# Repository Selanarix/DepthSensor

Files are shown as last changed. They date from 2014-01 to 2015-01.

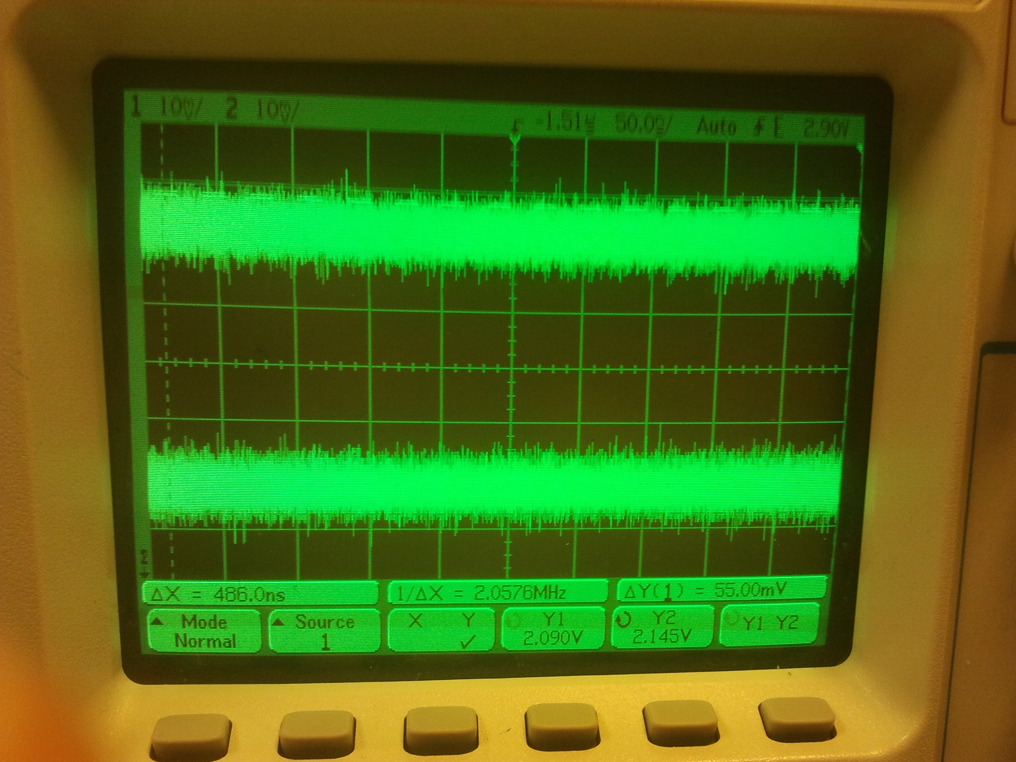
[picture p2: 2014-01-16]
pictures/MPX2100DP oszi/IMG_20140116_185502.jpg

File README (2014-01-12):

DepthSensor Project
====================

Copyright (c) 2014 Jonathan Schubert and Maximilian Hempe

About the repo
--------------
This repository contains code to realise a depth sensor by using an arduino uno and a differential pressure sensor. By transfering the pressure to water depth (1cm=1hPa) the arduino messures the water depth and gives it to a server, which produces a graph on a webpage. We do not give any garantee, but in tests it worked very well.

Purpose
--------
The Project should give a cost efficient method to messure the amount of water in an underground cistern. Additionally it can give statistics about water usage peak times.

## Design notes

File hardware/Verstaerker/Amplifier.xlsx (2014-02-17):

Messwerte Tempsensor Verstärker
(Gemessen mit Spannungsquelle anstelle des Sensors)
(909mV offset) | Ub | Ub in mV | Ua | Ua in mV | Formel (Ua*-0,5)+3,15 |  | Formel (Ua*-0,485)+3,1
 | 0.903 V | 903 mV | 4.483 V | 4483 mV | 0.909 V | 908.5 mV | 0.926 V | 925.745 mV
ca. 20°C | 1.108 V | 1108 mV | 4.055 V | 4055 mV | 1.123 V | 1122.5 mV | 1.133 V | 1133.325 mV
 | 1.004 V | 1004 mV | 4.234 V | 4234 mV | 1.033 V | 1033 mV | 1.047 V | 1046.51 mV
 | 1.200 V | 1200 mV | 3.824 V | 3824 mV | 1.238 V | 1238 mV | 1.245 V | 1245.36 mV
 | 1.401 V | 1401 mV | 3.400 V | 3400 mV | 1.450 V | 1450 mV | 1.451 V | 1451 mV
 | 1.603 V | 1603 mV | 2.972 V | 2972 mV | 1.664 V | 1664 mV | 1.659 V | 1658.58 mV
 | 1.700 V | 1700 mV | 2.768 V | 2768 mV | 1.766 V | 1766 mV | 1.758 V | 1757.52 mV
 | 1.801 V | 1801 mV | 2.552 V | 2552 mV | 1.874 V | 1874 mV | 1.862 V | 1862.28 mV
 | Ub | unverstärkt | verstärkt | delta
 | 850 mV | -3.41 °C | -4.20 °C | 0.79
 | 860 mV | -2.43 °C | -3.30 °C | 0.87
 | 870 mV | -1.45 °C | -2.20 °C | 0.75
 | 880 mV | -0.35 °C | -1.30 °C | 0.95
 | 890 mV | 0.50 °C | -0.33 °C | 0.83
 | 900 mV | 1.48 °C | 0.60 °C | 0.88
 | 910 mV | 2.58 °C | 1.75 °C | 0.83
 | 920 mV | 3.55 °C | 2.91 °C | 0.64
 | 930 mV | 4.54 °C | 3.70 °C | 0.84
 | 940 mV | 5.50 °C | 4.80 °C | 0.70
 | 950 mV | 6.60 °C | 5.78 °C | 0.82
 | 960 mV | 7.58 °C | 6.81 °C | 0.77
 | 970 mV | 8.56 °C | 7.91 °C | 0.65
 | 980 mV | 9.53 °C | 8.95 °C | 0.58
 | 990 mV | 10.51 °C | 10.17 °C | 0.34
 | 1000 mV | 11.98 °C | 11.33 °C | 0.65
 | 1100 mV | 21.86 °C | 21.89 °C | -0.03
 | 1200 mV | 32.12 °C | 32.20 °C | -0.08
 | 1300 mV | 42.00 °C | 42.80 °C | -0.80
 | 1400 mV | 52.89 °C | 52.90 °C | -0.01
 | 1500 mV | 62.15 °C | 64.13 °C | -1.98

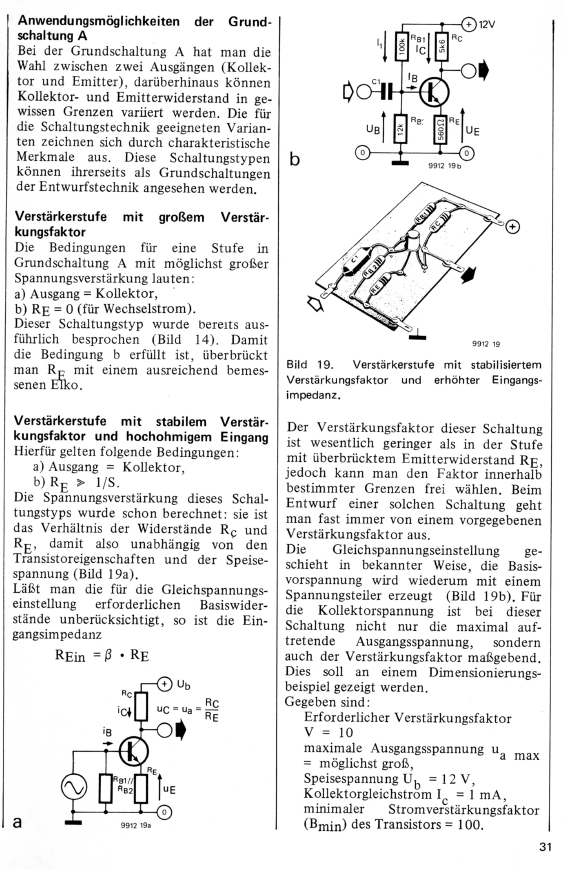
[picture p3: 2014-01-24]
hardware/Verstaerker/Verstaerker1.png

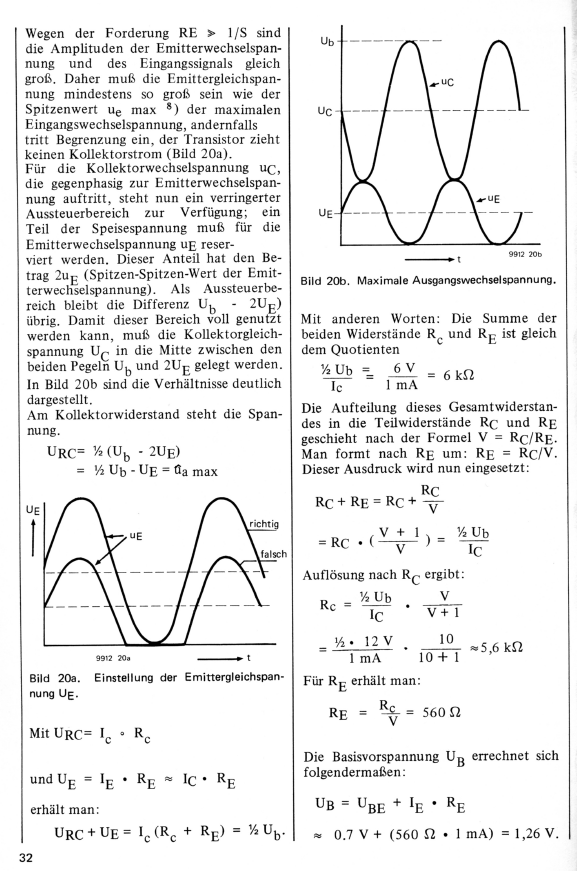
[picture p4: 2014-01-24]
hardware/Verstaerker/Verstaerker2.png

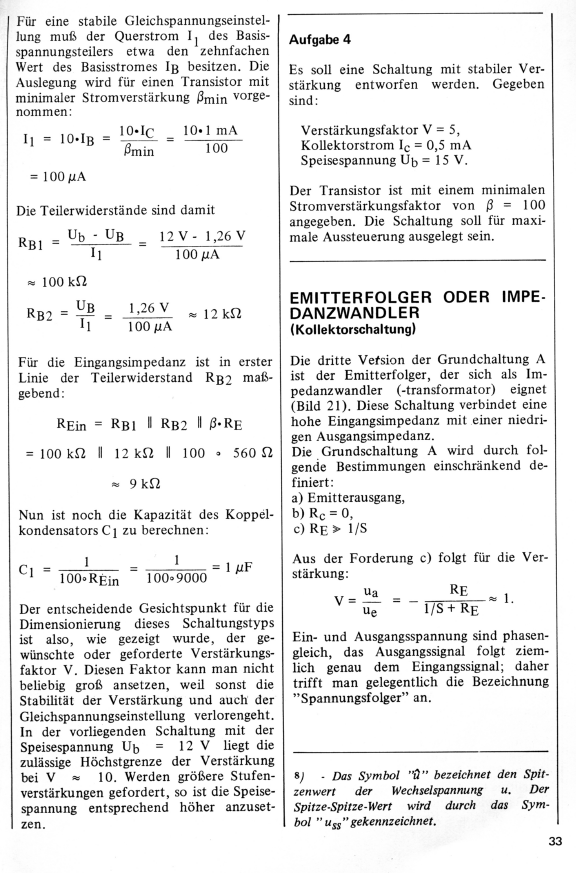
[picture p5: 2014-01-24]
hardware/Verstaerker/Verstaerker3.png

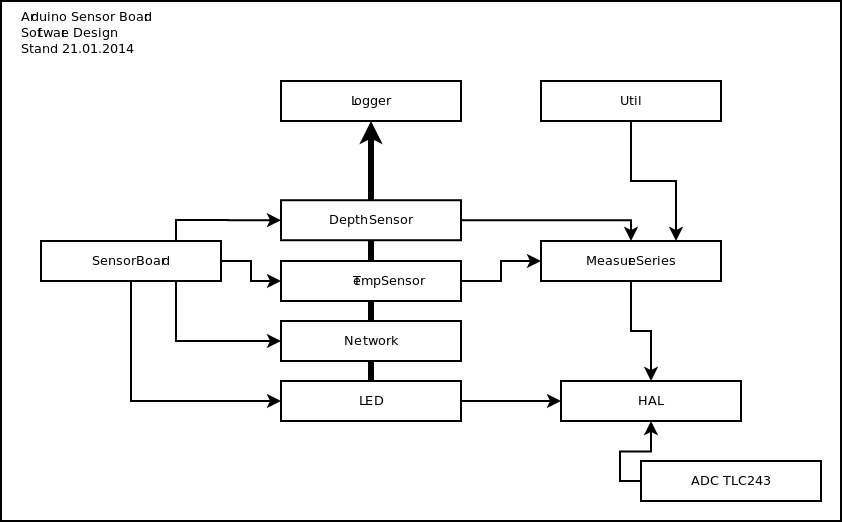
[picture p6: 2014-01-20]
sensorBoard/documentation/softwareDesign.png

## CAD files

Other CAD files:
hardware/Verstaerker/amplifier_npn.stl

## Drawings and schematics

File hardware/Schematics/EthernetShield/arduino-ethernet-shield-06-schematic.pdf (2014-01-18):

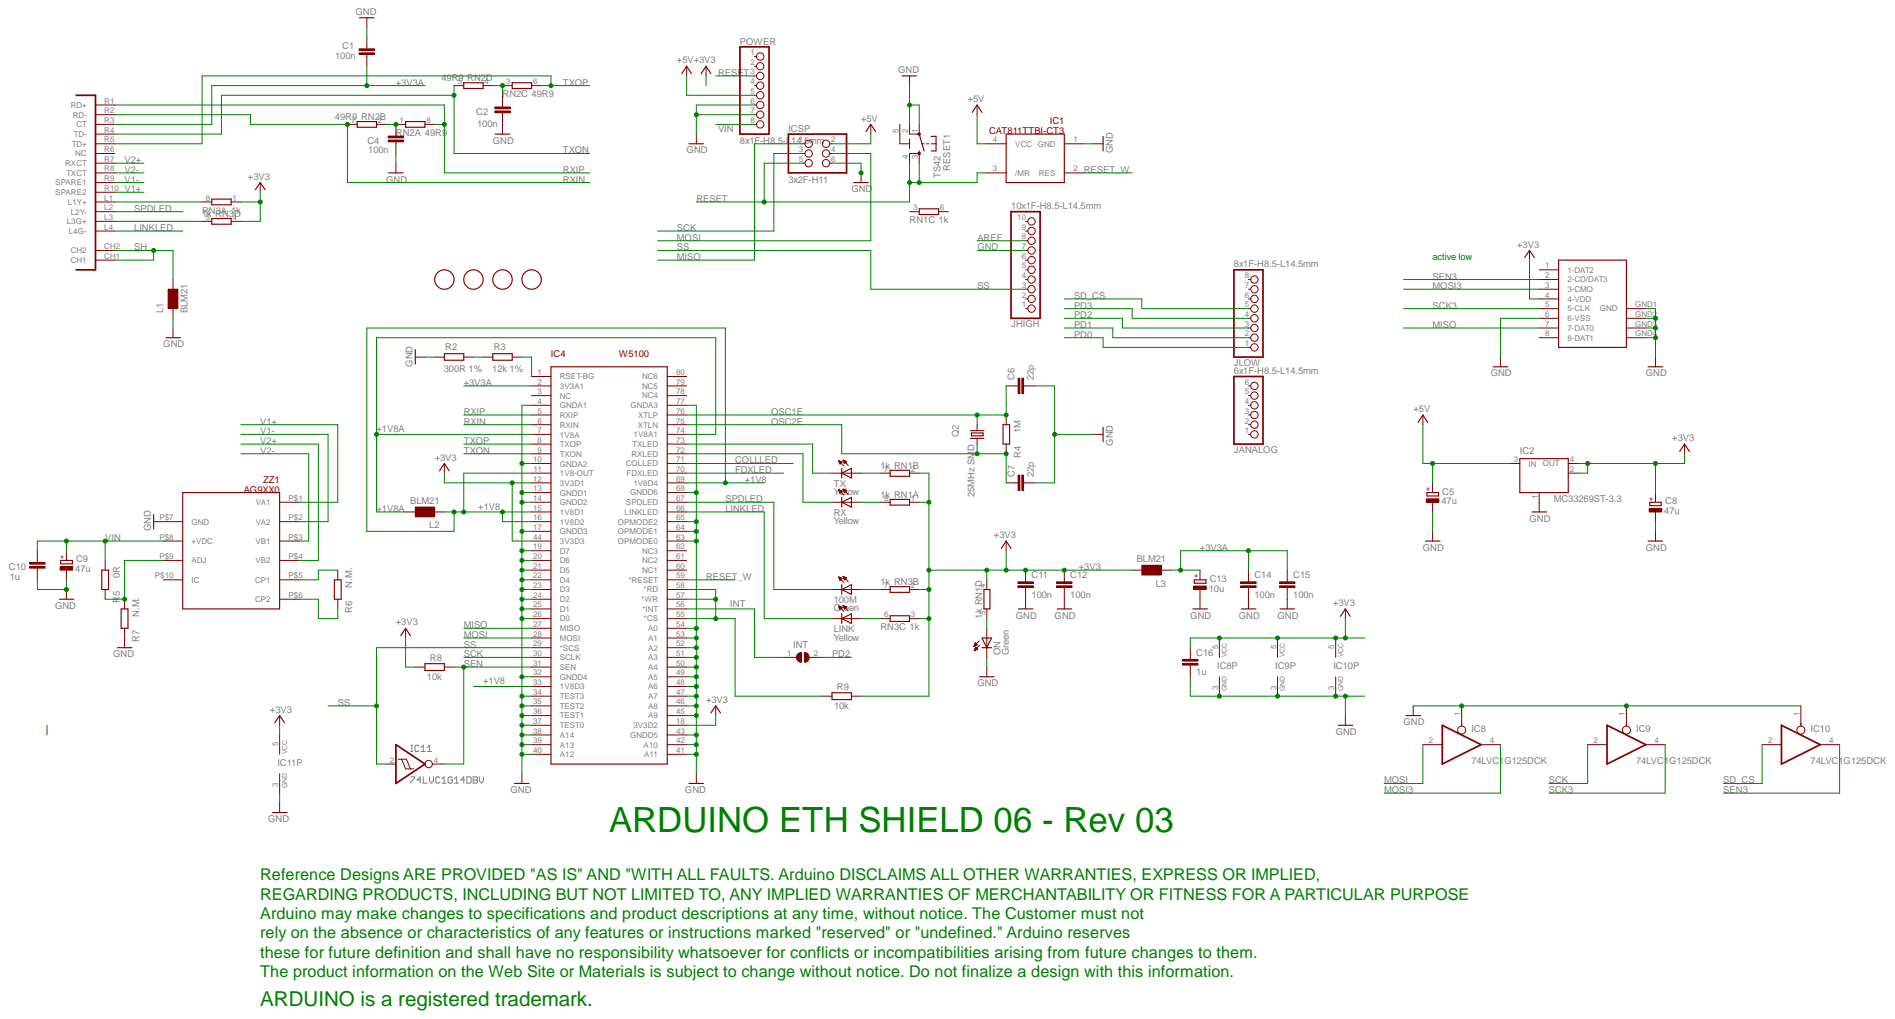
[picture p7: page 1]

ARDUINO ETH SHIELD 06 - Rev 03

Reference Designs ARE PROVIDED "AS IS" AND "WITH ALL FAULTS. Arduino DISCLAIMS ALL OTHER WARRANTIES, EXPRESS OR IMPLIED,
REGARDING PRODUCTS, INCLUDING BUT NOT LIMITED TO, ANY IMPLIED WARRANTIES OF MERCHANTABILITY OR FITNESS FOR A PARTICULAR PURPOSE
Arduino may make changes to specifications and product descriptions at any time, without notice. The Customer must not
rely on the absence or characteristics of any features or instructions marked "reserved" or "undefined." Arduino reserves
these for future definition and shall have no responsibility whatsoever for conflicts or incompatibilities arising from future changes to them.
The product information on the Web Site or Materials is subject to change without notice. Do not finalize a design with this information.
ARDUINO is a registered trademark.

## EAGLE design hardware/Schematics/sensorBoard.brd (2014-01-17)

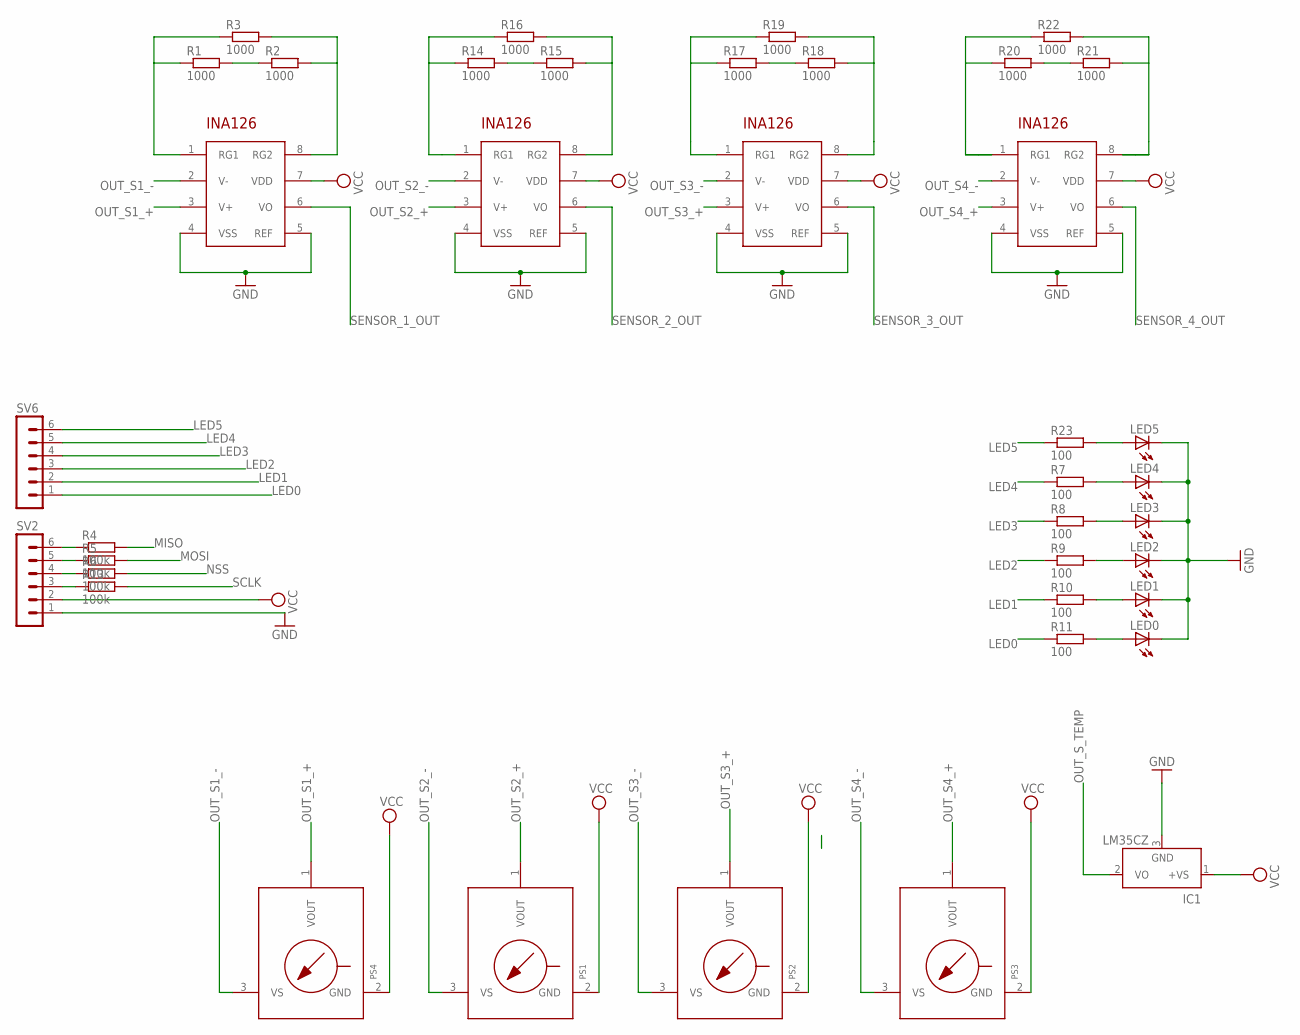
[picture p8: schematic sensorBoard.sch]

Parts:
IC1: LM35CZ; TO92
LED0, LED1, LED2, LED3, LED4, LED5: LED3MM
PS1, PS2, PS3, PS4: MPX-867B-H; 867B-H
R1, R2, R3, R14, R15, R16, R17, R18, R19, R20, R21, R22: 1000; R0603
R4, R5, R6, R13: 100k; R0603
R7, R8, R9, R10, R11, R23: 100; R0603
SV2, SV6: MA06-1
U$1, U$2, U$3, U$4: INA126; SO-08

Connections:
GND: IC1.3 (GND), LED0.K (C), LED1.K (C), LED2.K (C), LED3.K (C), LED4.K (C), LED5.K (C), SV2.1, U$1.4 (VSS), U$1.5 (REF), U$2.4 (VSS), U$2.5 (REF), U$3.4 (VSS), U$3.5 (REF), U$4.4 (VSS), U$4.5 (REF)
LED0: R11.1, SV6.1
LED1: R10.1, SV6.2
LED2: R9.1, SV6.3
LED3: R8.1, SV6.4
LED4: R7.1, SV6.5
LED5: R23.1, SV6.6
MISO: R4.1, R4.2, SV2.6
MOSI: R5.1, R5.2, SV2.5
unnamed: R2.2, R3.2, U$4.8 (RG2)
unnamed: R1.1, R3.1, U$4.1 (RG1)
unnamed: LED5.A, R23.2
unnamed: R15.2, R16.2, U$1.8 (RG2)
unnamed: R1.2, R2.1
unnamed: R14.1, R16.1
unnamed: R14.2, R15.1
unnamed: LED4.A, R7.2
unnamed: R17.1, R19.1, U$2.1 (RG1)
unnamed: LED3.A, R8.2
unnamed: LED2.A, R9.2
unnamed: LED1.A, R10.2
unnamed: LED0.A, R11.2
unnamed: R18.2, R19.2, U$2.8 (RG2)
unnamed: R20.1, R22.1, U$3.1 (RG1)
unnamed: R21.2, R22.2, U$3.8 (RG2)
unnamed: R17.2, R18.1
unnamed: R20.2, R21.1
NSS: R6.1, R6.2, SV2.4
OUT_S1_+: PS4.1 (VOUT)
OUT_S1_-: PS4.3 (VS)
OUT_S2_+: PS1.1 (VOUT)
OUT_S2_-: PS1.3 (VS)
OUT_S3_+: PS2.1 (VOUT)
OUT_S3_-: PS2.3 (VS)
OUT_S4_+: PS3.1 (VOUT)
OUT_S4_-: PS3.3 (VS)
OUT_S_TEMP: IC1.2 (VO)
SCLK: R13.1, R13.2, SV2.3
SENSOR_1_OUT: U$4.6 (VO)
SENSOR_2_OUT: U$1.6 (VO)
SENSOR_3_OUT: U$2.6 (VO)
SENSOR_4_OUT: U$3.6 (VO)
VCC: IC1.1 (+VS), PS1.2 (GND), PS2.2 (GND), PS3.2 (GND), PS4.2 (GND), SV2.2, U$1.7 (VDD), U$2.7 (VDD), U$3.7 (VDD), U$4.7 (VDD)

Board: 2 copper layers, 39 parts (18 on the bottom side), 30 nets, no tracks yet.

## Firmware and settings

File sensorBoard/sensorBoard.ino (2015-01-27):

#include "led.h"
#include "tempSensor.h"
#include "depthSensor.h"
//#include "network.h"
#include "logger.h"
#include "hal.h"
#include "sensor.h"
#include "realTimeClock.h"
#include "displayControl.h"

#define ONBOARD_DISPLAY 0

static boolean initialized = false;

// Set up temperatur sensor objects and their data
// ----------------------------------------------------------------------
const Sensor::SensorConstraints temperatureConstrain =
{
        -10.0, // MINIMAL_EXPECTED_SENSOR_VALUE;
        60.0, // MAXIMAL_EXPECTED_SENSOR_VALUE;
        2.0, // ALLOWED_TEST_SERIES_VARIATION;
        10.0 // MAX_ALLOWED_AVERAGED_VALUE_CHANGE;
};

const TestSeries::TestSeriesControll tempControll =
{
        5, // MAXIMAL_MEASUREMENT_RETRIES
        1000, // DELAY_FOR_RETRY_IF_SERIES_ERROR
        200 // DELAY_BETWEEN_MEASUREMENTS_ms
};

const Sensor::SensorConstData analogTemperatureConstData =
{
        0, //PIN
        5, //ID
};
const Sensor::SensorConstData digitalTemperatureConstData =
{
        0, //PIN
        10, //ID
}; 
// Set up depth sensor objects and their data
// ----------------------------------------------------------------------
const Sensor::SensorConstraints depthConstrain =
{
        -2.0, // MINIMAL_EXPECTED_SENSOR_VALUE;
        1000.0, // MAXIMAL_EXPECTED_SENSOR_VALUE;
        2.0, // ALLOWED_TEST_SERIES_VARIATION;
        20.0 // MAX_ALLOWED_AVERAGED_VALUE_CHANGE;
};

const TestSeries::TestSeriesControll depthControll =
{
        10, // MAXIMAL_MEASUREMENT_RETRIES
        5000, // DELAY_FOR_RETRY_IF_SERIES_ERROR
        1000 // DELAY_BETWEEN_MEASUREMENTS_ms
};

const Sensor::SensorConstData depthConst =
{
        1, //PIN
        0, //ID
};

TemperatureSensor::TemperatureSensor analogTemperature;
TemperatureSensor::TemperatureSensor digitalTemperature;
DepthSensor::DepthSensor depthSensor1;
TMP102::TMP102 tmp102;

void setup()
{
    ProjectLED::initLedPins();
    ProjectLED::LED_On(ProjectLED::LED0); //Indicate init procedure on board
    
#if ONBOARD_DISPLAY == 1
    DisplayControl::setUpDisplay();
#endif

    Logger::initLogger();
    Logger::changeOutputLogLevel(Logger::DEBUG);
        
    if(!HAL::initBaseHW())
    {
        Logger::log(Logger::ERROR,F("Could not set up HAL successfully"));
        return;
    }
    //Set up Sensors
    if(!TemperatureSensor::construct(&analogTemperature, &analogTemperatureConstData, &tempControll, &temperatureConstrain, TemperatureSensor::LM35, 5))
    {
        Logger::log(Logger::ERROR,F("Could not set up temperatur sensor"));
        return;
    }
    
    if(!TMP102::construct(&tmp102,TMP102::GND))
    {
        Logger::log(Logger::ERROR,F("Could not set up tmp102"));  
        return;
    } 
    if(!TemperatureSensor::constructDigital(&digitalTemperature, &digitalTemperatureConstData, &tempControll, &temperatureConstrain, TemperatureSensor::TMP102, 5, &tmp102))
    {
        Logger::log(Logger::ERROR,F("Could not set up digital temperature sensor"));
        return;
    }    
    if(!DepthSensor::construct(&depthSensor1, &depthConst, &depthControll, &depthConstrain, DepthSensor::MPX5100, 10))
    {
        Logger::log(Logger::ERROR,F("Could not set up depth sensor"));
        return;
    }   
    
    setUpRealTimeClock();
    //Network::initNetworkStack();
    Logger::log(Logger::INFO, F("System initialized"));
    ProjectLED::LED_Off(ProjectLED::LED0); //Indicate end of init on board
    initialized = true;
}

void showMeasurementDisplayView(Sensor::MeasurementResult tempRes, Sensor::MeasurementResult analogtempRes, Sensor::MeasurementResult depthRes,
                                TemperatureSensor::Temperature digiTemp, TemperatureSensor::Temperature analogTemp, DepthSensor::Depth depth)
{     
     Sensor::SensorStringInformation depthInfo = DepthSensor::sensorGetStringInfo();
     Sensor::SensorStringInformation tempInfo = TemperatureSensor::sensorGetStringInfo();
     
     DisplayControl::updatedepthMeasurementOutputSpace(DisplayControl::Space0, &depthInfo, depth);
     if(depthRes != Sensor::MeasurementOK)
         DisplayControl::setUpMeasurementWarning(DisplayControl::Space0);
     else
         DisplayControl::clearMeasurmentIcon(DisplayControl::Space0); 
     
     DisplayControl::updatedepthMeasurementOutputSpace(DisplayControl::Space1, &tempInfo, digiTemp);
     if(tempRes != Sensor::MeasurementOK)
         DisplayControl::setUpMeasurementWarning(DisplayControl::Space1);
     else
         DisplayControl::clearMeasurmentIcon(DisplayControl::Space1);
         
     DisplayControl::updatedepthMeasurementOutputSpace(DisplayControl::Space2, &tempInfo, analogTemp);
     if(analogtempRes != Sensor::MeasurementOK)
         DisplayControl::setUpMeasurementWarning(DisplayControl::Space2);
     else
         DisplayControl::clearMeasurmentIcon(DisplayControl::Space2);
}


void flashLED_1s()
{
    ProjectLED::LED_On(ProjectLED::LED0);
    delay(500);
    ProjectLED::LED_Off(ProjectLED::LED0);
    delay(500);
}

void cycleTask()
{
    //Only update system if waiting period is over already
    if(!isTimePeriodOver(32))
        return;
 
#if ONBOARD_DISPLAY == 1 
      DisplayControl::showIndicator(DisplayControl::MEASUREMENT);
#endif
    ProjectLED::LED_On(ProjectLED::LED0); //Measure LED
    //Measure sensors
    Sensor::MeasurementResult analogtempRes = TemperatureSensor::measureTemperature(&analogTemperature);
    Sensor::MeasurementResult digitaltempRes = TemperatureSensor::measureTemperature(&digitalTemperature);
    Sensor::MeasurementResult depthRes = DepthSensor::measureDepth(&depthSensor1);
    ProjectLED::LED_Off(ProjectLED::LED0); //Measure LED
#if ONBOARD_DISPLAY == 1       
      DisplayControl::hideIndicator(DisplayControl::MEASUREMENT);
#endif


    //Update sensor measurement results     
    TemperatureSensor::Temperature digiTemp= 0;
    TemperatureSensor::Temperature analogTemp= 0;
    DepthSensor::Depth depth = 0;
    
    if(digitaltempRes == Sensor::MeasurementOK)
        digiTemp = TemperatureSensor::getLastTemperature(&digitalTemperature);
    
    if(analogtempRes == Sensor::MeasurementOK)
        analogTemp = TemperatureSensor::getLastTemperature(&analogTemperature);
    
    if(depthRes == Sensor::MeasurementOK)
        depth = DepthSensor::getLastDepth(&depthSensor1);
    
     //Update display
#if ONBOARD_DISPLAY == 1
    //showMeasurementDisplayView(digitaltempRes, analogtempRes, depthRes, digiTemp, analogTemp, depth);
    if(DisplayControl::isNewLogInfo())
    {
         DisplayControl::showLogMessageScreen();
         delay(4000);
         DisplayControl::prepareStaticDisplay();
        // showMeasurementDisplayView(digitaltempRes, analogtempRes, depthRes, digiTemp, analogTemp, depth);
    }
#endif

#if ONBOARD_DISPLAY == 1 
     DisplayControl::showIndicator(DisplayControl::NETWORK);
     delay(1000);
     // Network::http_GET_Request(DepthSensor::getSensorID(&depthSensor1), depth);    
     DisplayControl::hideIndicator(DisplayControl::NETWORK);
#endif
   
    flashLED_1s(); 
}

void loop()
{
    if(!initialized)
    {
        Logger::log(Logger::ERROR, F("System error! Going to sleep for eternity"));
        delay(100);
        enterSleep(); //Sleep will never wake up here!
        return;
    }
    
    if(isRTC_FlagAndClear())
    {
        cycleTask();
        delay(100); //give HW some time to process last commands from task

        enterSleep();
    }
    else
    {
        Logger::log(Logger::ERROR,F("No power saving mode entered"));
    }
}

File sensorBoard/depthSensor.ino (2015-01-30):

#include "depthSensor.h"  
#include "logger.h"
#include "sensorErrorTypes.h"

namespace DepthSensor 
{
    //-------------------------- Private Types -------------------------------------
    //-------------------- Private Function Prototypes -----------------------------

    void readMPX5500Sensor(double* measurementOfSeries, const void* b);
    void readMPX5100Sensor(double* measurementOfSeries, const void* c);
    static inline Depth roundToDepth(double);
      

    TestSeries::TestSeriesCheckResult testTestSeries(const TestSeries::TestSeries* s, const Sensor::SensorConstraints* con);
    bool testEvaluatedValue(const DepthSensor* con, const Depth dep);

    static void logDepthTestSeriesError(SensorError::TestSeriesError an);
    static void logAverageDepthErrors(SensorError::AverageMeasurementError b);

    //------------------------ Private Data ----------------------------------------
    //------------------------ Read only -------------------------------------------
    static const char* sensorNames[] = 
    {
      "MPX5500",
      "MPX5100"
    };
    
    //------------------------ Public Functions ------------------------------------
    bool construct(DepthSensor* tSen, 
                    const Sensor::SensorConstData* constDa, 
                    const TestSeries::TestSeriesControll* controll,
                    const Sensor::SensorConstraints* cons, 
                    DepthSensorType t, uint32_t size)
    {
        if(tSen == NULL || constDa == NULL || controll == NULL || cons == NULL)
            return false;
 
        tSen->lastDepth = 0.0;
        tSen->constrains = cons;
        tSen->constData = constDa;
        tSen->type = t;
  
        switch(t)
        {
            case MPX5500:
                return TestSeries::construct(&(tSen->series),  controll, readMPX5500Sensor, testTestSeries, size); 
            case MPX5100:
                return TestSeries::construct(&(tSen->series),  controll, readMPX5100Sensor, testTestSeries, size); 
        }
  
        return false;
    }    

    uint8_t getSensorID(const DepthSensor* con)
    {
          if(con == NULL)
              return 0;
          return con->constData->ID;
    }

    Depth getLastDepth(const DepthSensor* con)
    {
          if(con == NULL)
              return 0;
          return con->lastDepth;
    }
    
    const Sensor::SensorStringInformation sensorGetStringInfo()
    {
       Sensor::SensorStringInformation res = 
       {
          F("Depth: "),
          UNIT_cm
       };
       return res;
    }
    
    void initDepthSensorHW(const DepthSensor* con)
    {
        //pinMode(con->getPin((Sensor::Sensor*)con),INPUT);
        Logger::log(Logger::INFO, F("depth sensor initialized"));
    }

    Sensor::MeasurementResult measureDepth(DepthSensor* pSen)
    {
        if(pSen == NULL)
        {
            Logger::log(Logger::ERROR,F("Can not measure for null instance of depth sensor"));
            return Sensor::MeasurementError;
        }    
            
        Logger::printSeperator();//------------------------------------------
        Logger::logString(Logger::INFO, F("Measure depth sensor: "), sensorNames[pSen->type]);
        Logger::logInt(Logger::DEBUG, F("Sensor id: "),(uint32_t)pSen->constData->ID);
        TestSeries::TestSeriesCheckResult res = TestSeries::takeTestSeries(&(pSen->series), pSen->constrains, pSen);

        if(res != TestSeries::TestSeriesOK)
        {
            Logger::log(Logger::ERROR,F("Could not measure depth"));
            Logger::printSeperator();//------------------------------------------
            pSen->lastDepth = 0.0;
            return Sensor::MeasurementError;
        }
	    //Process data out of test series
        Sensor::MeasurementResult result = Sensor::MeasurementOK;
        Depth avgDepthOfSeries = roundToDepth(TestSeries::getAverageMeanOfSeries(&(pSen->series)));
      
        //Keep sensor value but generate callback if not as acpected. 
        if(!testEvaluatedValue(pSen,avgDepthOfSeries))
            result = Sensor::MeasurementValueUnexpected;

        Logger::logInt(Logger::INFO, F("Tiefe [cm]: "), avgDepthOfSeries);
        Logger::printSeperator();//------------------------------------------
        pSen->lastDepth = avgDepthOfSeries;
        return result;
    }

    //------------------------------ Private Functions -----------------------------
    void readMPX5100Sensor(double* measurementOfSeries, const void* ob)
    {
        //read value from sensor and assign it to measurementOfSeries
        double sensor_mV = 0.0;
        const double offset = 190.0;
        
        if(ob == NULL)
            return;
            
        const DepthSensor* thi = (DepthSensor*)ob;
          
        //Formel aus Datenblatt (in kPa): Vout = Vs*(0,009*p+0,04)        
        //Umgestellt nach p (in hPa!!): p=(Vout-200)/4.5
     sensor_mV = (double)HAL::analogReadVoltage(thi->constData->PIN);
        *measurementOfSeries = (sensor_mV-offset)/3.88;

    }

    void readMPX5500Sensor(double* measurementOfSeries, const void* ob)
    {
        //read value from sensor and assign it to measurementOfSeries
        double pressure = 0.0;
        double adcvalue = 0.0;
        double sensorVoltageADC = 0.0;
        const double offset = 0.180;
        
        if(ob == NULL)
            return;
        
        const DepthSensor* thi = (DepthSensor*)ob;
        
        adcvalue = (double)HAL::analogReadPin(thi->constData->PIN);
        sensorVoltageADC = (adcvalue)*(5.0/4096.0);
        pressure = (sensorVoltageADC-offset)*1111;
        
	*measurementOfSeries = pressure;
    }

    TestSeries::TestSeriesCheckResult testTestSeries(const TestSeries::TestSeries* s, const Sensor::SensorConstraints* con)
    { 
        if(s == NULL || con == NULL)
            return TestSeries::TestSeriesCancelMeasurement;

        using namespace SensorError;

        TestSeriesError errorTypes = TestSeriesOK;
        TestSeries::MinMax res = TestSeries::evaluateMinMaxOfTestSeries(s);

        double meanVariation = res.max - res.min;
        if(res.min < 0.0001 && res.max < 0.0001)
            errorTypes = SensorOutOfFunction;
        else if(res.min < con->MINIMAL_EXPECTED_SENSOR_VALUE)
            errorTypes = TestSeriesUnderMinRange;
        else if(res.max > con->MAXIMAL_EXPECTED_SENSOR_VALUE)
            errorTypes = TestSeriesAboveMaxRange;
        else if(meanVariation > con->ALLOWED_TEST_SERIES_VARIATION)
            errorTypes = TestSeriesMeanVariationToBig;

        logDepthTestSeriesError(errorTypes);
 
        if(errorTypes == SensorOutOfFunction)
            return TestSeries::TestSeriesCancelMeasurement; //Cancel further       
        if(errorTypes != TestSeriesOK)
            return TestSeries::TestSeriesInvalid;
            
	    return TestSeries::TestSeriesOK;
    }
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

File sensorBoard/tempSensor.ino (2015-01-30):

#include "tempSensor.h"
#include "logger.h"
#include "sensorErrorTypes.h"
#include "hal.h"

namespace TemperatureSensor
{
    //-------------------------- Private Types -------------------------------------
    //-------------------- Private Function Prototypes -----------------------------
    void readLM35(double* mes, const void*);
    void readTMP_102(double* mes, const void*);
    TestSeries::TestSeriesCheckResult testTestSeries(const TestSeries::TestSeries* s, const Sensor::SensorConstraints* con);
    bool testEvaluatedValue(const TemperatureSensor* sen,const Temperature dep);
    
    static void logTemperaturTestSeriesError(SensorError::TestSeriesError ab);
    static void logAverageTemperaturErrors(SensorError::AverageMeasurementError b);
    
    //------------------------ Private Data ----------------------------------------
    //------------------------ Read only -------------------------------------------
    const char* sensorNames [] = 
    {
        "LM35",
        "TMP_102"
    };
    //------------------------ Public Functions ------------------------------------
    
    bool construct(TemperatureSensor* tSen, 
                    const Sensor::SensorConstData* constDa, 
                    const TestSeries::TestSeriesControll* controll,
                    const Sensor::SensorConstraints* cons, 
                    TemperatureSensorType t, uint32_t size)
    {
        if(tSen == NULL || constDa == NULL || controll == NULL || cons == NULL)
            return false;
    
        tSen->lastTemperature = 0.0;
        tSen->constrains = cons;
        tSen->constData = constDa;    
        tSen->type = t;    
        tSen->digitalSensor = NULL;
        switch(t)
        {
            case LM35:
                return TestSeries::construct(&(tSen->series),  controll, readLM35, testTestSeries, size);  
                
            case TMP102:
                return true;
        }              
        return false; 
    }
    
    bool constructDigital(TemperatureSensor* tSen, 
                    const Sensor::SensorConstData* constDa, 
                    const TestSeries::TestSeriesControll* controll,
                    const Sensor::SensorConstraints* cons, 
                    TemperatureSensorType t, uint32_t size, TMP102::TMP102* sen)
    {
        if(sen == NULL)
            return false;
            
        if(!construct(tSen,constDa,controll, cons, t,size))
            return false;
            
        tSen->digitalSensor = sen;
        
        return TestSeries::construct(&(tSen->series),  controll, readTMP_102, testTestSeries, size);
    }
    
    const Sensor::SensorStringInformation sensorGetStringInfo()
    {
       Sensor::SensorStringInformation res =
       {
          F("Temp: "),
          UNIT_degC
       };
       return res;
    }
   
    uint8_t getSensorID(const TemperatureSensor* con)
    {
         if(con == NULL)
              return 0;
         return con->constData->ID;
    }
    
    Temperature getLastTemperature(const TemperatureSensor* con)
    {
         if(con == NULL)
              return 0;
         return con->lastTemperature;
    }
    
    void initTemperatureSensorHW(const TemperatureSensor* con)
    {
        Logger::log(Logger::INFO, F("temperatur sensor initialized"));
    }
    
    Sensor::MeasurementResult measureTemperature(TemperatureSensor* tSen)
    {
        if(tSen == NULL)
        {
            Logger::log(Logger::ERROR,F("Can not measure for null instance of temperatur sensor"));
            return Sensor::MeasurementError;
        }    
        Logger::printSeperator();//------------------------------------------
        Logger::logString(Logger::INFO, F("Measure temperature sensor: "), sensorNames[tSen->type]);
        Logger::logInt(Logger::DEBUG, F("Sensor id: "),(uint32_t)tSen->constData->ID);
        TestSeries::TestSeriesCheckResult res = TestSeries::takeTestSeries(&(tSen->series), tSen->constrains, tSen);
        
        if(res != TestSeries::TestSeriesOK)
        {
           Logger::log(Logger::ERROR,F("Could not measure temperature"));
           Logger::printSeperator();//------------------------------------------
           tSen->lastTemperature = 0.0;
           return Sensor::MeasurementError;
        }
        Sensor::MeasurementResult result = Sensor::MeasurementOK;
        Temperature avgTemperaturOfSeries = (Temperature)TestSeries::getAverageMeanOfSeries(&(tSen->series));
       
        //Keep sensor value but generate callback if not as acpected. 
        if(!testEvaluatedValue(tSen,avgTemperaturOfSeries))
            result = Sensor::MeasurementValueUnexpected;
    
        Logger::logInt(Logger::INFO, F("Temperatur [C]: "), avgTemperaturOfSeries);
        Logger::printSeperator();//------------------------------------------
        tSen->lastTemperature = avgTemperaturOfSeries;
        return result;
    }
    
    
    //------------------------------ Private Functions -----------------------------
    void readLM35(double* mes, const void* ob)
    {
       if(ob == NULL)
           return;
     
        const TemperatureSensor* thi = (TemperatureSensor*)ob;
        
        double sensor_mV = (double)HAL::analogReadVoltage(thi->constData->PIN);
        *mes = (sensor_mV*-0.485)+3100; //amplified->non-amplified
        *mes = (*mes-909)/10.0; //minus diode offset and 10mV/degree
    }  
    
    void readTMP_102(double* mes, const void* ob)
    {
        if(ob == NULL)
            return;
      
        const TemperatureSensor* thi = (TemperatureSensor*)ob;
        if(thi->digitalSensor == NULL)
            return;
    
        *mes = TMP102::simpleRead(thi->digitalSensor);
    }  
    
    TestSeries::TestSeriesCheckResult testTestSeries(const TestSeries::TestSeries* s, const Sensor::SensorConstraints* con)
    { 
        if(s == NULL || con == NULL)
            return TestSeries::TestSeriesCancelMeasurement;
    
        using namespace SensorError;
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

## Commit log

2014-01-09 add datasheet of sensor
2014-01-10 check in of "arduino project" -depthSensor.ino file must be in depthSensor directory! -Header must be somewhere in the depthSensor directory
2014-01-10 Analog Input transformed to kPa (does not work propper)
    [depthSensor.ino]
2014-01-10 add graph drawing framework
    [CO2.csv, bulkdata.csv, datawithtitle.csv]
2014-01-12 -Corrected pressure formula -output in V, hPa and cm (hPa=cm)
    [depthSensor.ino]
2014-01-12 add datasheet of new sensor
2014-01-12 -Code for LAN Board (not finished)
2014-01-13 cleared php errors in index.php missing: label of x-axis
2014-01-13 -Arduino Network konfig is working -PUT on Arduino works with server IP -Statistics on WebFrontend are working
2014-01-13 changed project structure of web folder. Added javascript for autoreload of image. Remove unused example code
    [CO2.csv, bulkdata.csv, datawithtitle.csv]
2014-01-13 generate log and sensorData folder
2014-01-13 change percentage calculation of the dynamic tank image. Fixed mapping in central data structure between sensor ID and sensor data was random before... My fault sry
2014-01-13 -include of header and footer in Frontend -statistics for multiple SensorData
2014-01-15 added first aproach of an sensor board. Not ready yet. Just first aproach. ADC is missing and Opamp isn't connected yet
    [sensorBoard.brd, sensorBoard.sch]
2014-01-15 added two new fields to xml for sensor type and its unit.
2014-01-15 -basic function for temp sensor -corrected regular update in webFrontend
    [depthSensor.ino]
2014-01-16 print debug info to serial
2014-01-16 wired amplifier and start to set up SPI for ADC in schematic
    [sensorBoard.brd, sensorBoard.sch]
2014-01-16 add first aproach of HAL for arduino platform. This allows simple transformation for other platforms.
2014-01-16 Statistics without fixed Y-Axis Statistics: Y-Axis gets description from xml file
    [network.ino]
2014-01-16 add images of oszi showing problem with sensor MPX2100
2014-01-16 -basic function for new pressure sensor MPX2100DP
2014-01-16 change display for different sensor types. Changed name from depthMeasurements to measurements to stay more generally
2014-01-17 build sensor sandwich board to get it smaller. Still waiting for the ADC we would like to use
    [sensorBoard.brd, sensorBoard.sch]
2014-01-17 added volume information to tank image. Avoid img tag placement for tank image in case of temperatur sensor
2014-01-18 -basic function for external adc (8bit) with spi and cs on pin9 (only working without ethernet shield)
2014-01-18 Schematics of Ethernet Shield and Arduino r3 (we use r2 but it is quite similar)
2014-01-18 integrated logger to rest of project. Completed first version of hal for arduino
2014-01-20 own folder for sensorBoard PCB
    [sensorBoard.brd, sensorBoard.sch]
2014-01-20 -basic function for 12bit ADC connected over SPI -Roadmap for further ideas to implement
2014-01-20 add first software design diagram for arduino. Start writing driver vor ADC
2014-01-21 Changes in WebFrontend: -no more carousel classes in Header -watertanks in Header are aligned -seperated statistics per SensorType -auto links in Dropdown at Statistics Menu in NavigationBar -auto-fo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
2014-01-21 export testSeries methods to stay general for different sensors. Add driver for ADC. All componentsuntested atm.
2014-01-23 changes for propper working ADC (made in Lab)
2014-01-24 start to set up for new depth sensor test
2014-01-24 1.fixed bugs in ADC driver for ADC test by introducing warm up delay. 2. Tested and integrated testSeries abstraction to depth and temperature sensor 3. write temperatur sensor based on this abstract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
    [ADC_tlc243.ino, depthSensor.ino, sensorBoard.ino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]
2014-01-27 set up hal basic function without using arduino framework. Set up HAL for external ADC reading. Start to use only function from my HAL instead of arduino framework.
2014-01-27 add parameter for depth sensor to differ between sensor types. Read function of sensor is now sensor dependent.
2014-01-27 Analog Amplifier with Simulation and Messurements
    [Amplifier.xlsx, amplifier_npn.sch, amplifier_npn.stl]
2014-01-31 add critical section while spi communication
2014-01-31 start writing driver for temperatur sensor
2014-01-31 change sensor functions to use oop methods. Sensor under simulation mode atm.
2014-02-01 start writing driver for TMP102 temperature sensor board using I2C
2014-02-02 completed driver for tmp102. Still untested
2014-02-02 try to use new sensor functionality out of main. Is not working atm
    [TMP_102.ino, depthSensor.ino, sensorBoard.ino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]
2014-02-03 Move log messages to flash by using F(). Rewrite testSeries and temperatur Sensor. Untested atm
2014-02-03 Messergebnisse der Verstärkerschaltung (Temp Sensor)
    [Amplifier.xlsx]
2014-02-03 Moved strings of log messages to flash by using F(). Rewrote depth sensor to fit the into the new structure. Fixed all compiler errors. Next step is testing on platform
    [depthSensor.ino, logger.ino, sensorBoard.ino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]
2014-02-04 add support for hil to the sensors. At them moment they are not using HAL because of test data out of static variable
2014-02-04 function for new MPX5100GP Sensor
2014-02-04 Change structure to allow measure method to access object's data. Add temp sensor support for TMP102.
2014-02-04 import of readSensor-Function for Pressure Sensor mpx5100 changes to make solution compilable
2014-02-04 change depth sensor to fit new function pointer for measure functions
2014-02-07 add small bug with false error log for average measurement
    [depthSensor.ino]
2014-02-09 formula for mxp5100 (adc->cm)
2014-02-10 init checkin for display driver. Add method to read directly millivolt from the HAL
2014-02-10 test and fix bugs in temperature sensor driver
    [TMP_102.ino, sensorBoard.ino]
2014-02-12 add debug level for measurement result in test series. Formular of temperature from sensor is not correct
    [depthSensor.ino, sensorBoard.ino, tempSensor.ino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]
2014-02-12 Formula for lm35 with ampifier
    [Amplifier.xlsx]
2014-02-12 add digital temperatur sensor to sensorBoard to compare analog value
2014-02-14 add functions for display driver. New global seperator line in logger
2014-02-17 New formula for calculating amplified temp sensor
    [Amplifier.xlsx, amplifier_npn.sch]
2014-02-17 -Test with new Temp Formula and different tubes -rounding of depth average
2014-02-18 add name of sensor to debug output. Test successfull init system check for main loop
2014-03-04 fix bug with flash string in display driver. Problem with the deleting writing on display still unsolved
    [depthSensor.ino, display.ino, displayControl.ino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]
2014-03-05 fix bug in display driver with or and xor. moved strings to flash in general types file. Still problem with clearing chars after writing
    [depthSensor.ino, displayControl.ino, sensorBoard.ino]
2014-03-14 fix bug with overwriting chars in display driver. Add main to display measurement on display
    [ADC_tlc243.ino, display.ino, displayControl.ino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]
2014-03-14 add macro to enable disable display functionality. Error management on display is still not finish
    [sensorBoard.ino]
2015-01-27 modify project
    [Amplifier.xlsx, amplifier_npn.sch, amplifier_npn.stl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]
2015-01-27 project cleanup
    [Amplifier.xlsx, amplifier_npn.sch, amplifier_npn.stl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]
2015-01-30 Add missing source file. Try to solve problem with file rights.
    [Amplifier.xlsx, amplifier_npn.sch, amplifier_npn.stl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]
